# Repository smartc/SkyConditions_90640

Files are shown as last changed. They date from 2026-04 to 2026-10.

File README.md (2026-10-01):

# SkyConditions_90640

ESP32-S3 ASCOM Alpaca **ObservingConditions** device using an MLX90640 32×24 infrared thermal camera and TSL2591 sky brightness sensor.  Provides a fully standards-compliant Alpaca API for sky temperature, cloud cover, sky brightness, and sky quality monitoring — plus a live thermal viewer and trend charts in the browser.

**Current version: 0.6.3**

---

## Features

- **ASCOM Alpaca ObservingConditions** (device 0, port 11111, Interface v1)
  - SkyTemperature, Temperature, CloudCover, SkyBrightness, SkyQuality, Humidity (when DHT/BME280 enabled)
  - TimeSinceLastUpdate (all sensors, including LatestUpdateTime via empty SensorName)
  - SensorDescription, AveragePeriod, Refresh
- **ASCOM Alpaca SafetyMonitor** (device 0, port 11111, Interface v1)
  - IsSafe backed by rain/snow relay sensor; hidden from discovery when rain sensor is disabled
- **ASCOM Alpaca Switch** (device 0, port 11111, ISwitchV2)
  - One read-only analog switch: cloud cover percentage (0–100%), GetSwitch=true when ≥ 50%
- **UDP discovery** on port 32227 — runs on FreeRTOS Core 0 (independent of sensor reads)
- **Dual cloud cover calculation**
  - *Mean method*: linear interpolation on the center-FOV average ambient−sky delta
  - *Per-pixel method*: per-pixel interpolation across a configurable region, then averaged
  - Both methods trended simultaneously; Setup page toggle selects which value is reported to Alpaca
  - Live thermal view bounding box tracks the configured per-pixel region
- **Optional rain / snow sensor** — two-pin relay detection; relay closure = wet
- **DDA-compatible Safety Sensor UDP broadcast** — periodically broadcasts rain safety status on the local subnet in the Dark Dragon Astronomy park-sensor JSON format, allowing devices such as a Roll-Off Roof controller to discover the sensor and react to weather conditions automatically; port, interval, and enable state are runtime-configurable
- **Optional ambient sensor** — runtime-selectable: DHT11, DHT22, BMP180, BMP280, or BME280; replaces MLX90640 die temp as ambient reference for cloud cover calculations
- **MQTT / Home Assistant autodiscovery** — publishes all sensor values + thermal thumbnail; HA entities created automatically on connect
- **ClearDarkSky colormap** for the thermal heatmap — dark navy (clear/cold) through white (overcast/warm), anchored to calibration thresholds (floating) or a fixed °C range with a warm tail (default −45 … +60 °C, ending in red); a colour bar beside the live view shows the scale
- **Live thermal WebSocket stream** on port 81 — 784-byte binary frames at 2 Hz, bicubic-smoothed in the browser
- **Browser UI** on port 80
  - Home page: current readings, live thermal image, dual cloud cover values, brightness, rain status, humidity
  - Trends page: 60-min and 24-h charts for all sensors
  - Sky History page (`/skyhistory`): 90-day month calendar with Rain / SQM (night) / Clear Sky views — accumulated rain duration, night sky-quality average & peak, and day/night clear-sky hours — in the browser's local time zone, with CSV export
  - Setup page: full calibration, sensor enable/type selection, MQTT, NTP, network settings, WiFi scan & reconnect
  - Debug console (`/console`): live serial log with deduplication and copy button
- **Raw thermal matrix endpoint** — `GET /thermalmatrix` returns the full 32×24 temperature array as JSON
- **OTA firmware updates** via ElegantOTA at `/update`
- **WiFi management** — scan for networks and reconnect without a full credential reset (Setup page → WiFi)
- **History ring buffers**: 30-second buckets (60 min hi-res) + 15-minute buckets (24 h lo-res)
- **Persistent sky history**: hourly rain wet-time, night SQM avg/peak, and day/night clear-sky-hours logs covering 90 days, survives reboot, backing the Sky History calendar
- Persistent configuration in NVS flash (survives reboots)
- Passes ASCOM Conform Universal 4.2.1 with **0 errors, 0 issues** on all three devices

---

## Hardware

### Supported Boards

| Board | Notes |
|---|---|
| **Seeed XIAO ESP32-S3 Sense Plus** + Grove Shield | Primary target (`#define BOARD_XIAO_SENSE` in `config.h`) |
| ESP32-S3 Dev Module | Alternate; comment out `BOARD_XIAO_SENSE` |

Enable **PSRAM** in board settings — the thermal JPEG staging buffer requires ~230 KB.

### Sensors

| Component | Part | I2C Address |
|---|---|---|
| Thermal camera | Melexis MLX90640 32×24 IR array | 0x33 |
| Sky brightness | AMS TSL2591 | 0x29 |
| Ambient (optional) | DHT11 / DHT22 / BMP180 / BMP280 / BME280 | GPIO or I2C |

### Wiring (XIAO ESP32-S3 Sense + Grove Shield)

| Signal | XIAO Pin | GPIO |
|---|---|---|
| I2C SDA | D4 | GPIO 5 |
| I2C SCL | D5 | GPIO 6 |
| Rain relay drive | D8 | GPIO 7 |
| Rain relay sense | D9 | GPIO 8 |
| DHT data | D7 | GPIO 44 |

The rain sensor uses two pins: drive pin is held OUTPUT HIGH; relay closure pulls the sense pin HIGH (INPUT_PULLDOWN).  No external components required.

BMP180 / BMP280 / BME280 share the existing I2C bus — no extra GPIO needed.

### Wiring (ESP32-S3 Dev Module)

| Signal | GPIO |
|---|---|
| I2C SDA | GPIO 8 |
| I2C SCL | GPIO 9 |

---

## 3D-Printed Enclosure

The `Enclosure/` directory contains STL files and a master 3MF project for the weatherproof housing.  The design is sized for a **Seeed XIAO ESP32-S3** mounted on the **Grove Expansion Board**.

### Print Files

| File | Material | Notes |
|---|---|---|
| `Housing - Base.stl` | ASA or PETG | Main enclosure body |
| `Housing - Top.stl` | ASA or PETG | Lid |
| `Housing - Bracket.stl` | ASA or PETG | Mounting bracket |
| `Housing - Bracket Clamp.stl` | ASA or PETG | Bracket clamp |
| `Housing - Plug.stl` | ASA or PETG | Port plug |
| `Sensor Insert Plate.stl` | ASA or PETG | Sensor mounting plate |
| `Stevenson Screen.stl` | ASA or PETG | Stevenson radiation shield (requires supports) |
| `Stevenson Screen - Base Cap.stl` | ASA or PETG | Base cap for Stevenson screen |
| `TPU Housing Body Gasket.stl` | TPU | Weatherproof lid seal |
| `TPU Sensor Insert Gasket.stl` | TPU | Sensor plate seal |
| `TPU Cable Grommet.stl` | TPU | Cable entry grommet |
| `Sky Conditions 90640 - Enclosure.3mf` | — | Master 3MF project (all parts, orientations, materials) |

### Assembly Notes

- **Material:** Print structural parts in **ASA** (preferred outdoors) or **PETG**.  Print gaskets and grommets in **TPU**.
- **Stevenson screen:** Requires supports due to overhangs.
- **Heatset inserts required:**

  | Size | Location |
  |------|----------|
  | M3 | Lid-to-body and bracket fasteners |
  | M2.5 | PCB/expansion board mounting |
  | M2 | Sensor plate and smaller internal fasteners |

- **Fasteners:** Matching M3 / M2.5 / M2 socket-head or pan-head screws.
- **Lens holder:** The Uxcell 20 mm LED lens holder is glued into the top of the housing directly over the TSL2591.
- **Strain relief:** A 3/8″ PVC strain relief fitting is used for the MLX90640 cable entry.

---

## Bill of Materials

| Component | Part | Notes |
|---|---|---|
| Microcontroller | Seeed XIAO ESP32-S3 | |
| Expansion board | Seeed Grove Expansion Board for XIAO | Provides I2C headers and convenient wiring |
| Thermal camera | MLX90640 (TO-92 can format) | I2C, 32×24 IR array |
| Sky brightness | Adafruit TSL2591 | I2C, auto-gain |
| Rain / snow sensor | Relay-based heated sensor | [AliExpress](https://www.aliexpress.com/item/1005005479538840.html) |
| Lens holder | Uxcell 20 mm LED lens holder | [Amazon](https://a.co/d/01UBlwtW) — glued over TSL2591 aperture |
| Strain relief | 3/8″ PVC strain relief fitting | MLX90640 cable entry |
| Hookup wire | 22–26 AWG | I2C bus, sensor connections |

---

## Required Libraries

Install via Arduino IDE Library Manager unless noted:

| Library | Source |
|---|---|
| Adafruit MLX90640 | Library Manager |
| Adafruit TSL2591 | Library Manager |
| Adafruit BMP085 Unified | Library Manager (BMP180 support) |
| Adafruit BMP280 | Library Manager (BMP280 support) |
| Adafruit BME280 | Library Manager (BME280 support) |
| DHT sensor library (Adafruit) | Library Manager |
| WiFiManager (tzapu) | Library Manager |
| arduinoWebSockets (Markus Sattler) | Library Manager |
| ElegantOTA | Library Manager |
| ArduinoJson | Library Manager |
| **PubSubClient** | **Bundled** — `PubSubClient.h/.cpp` in project root |

---

## Build & Flash

1. Open `SkyConditions_90640.ino` in Arduino IDE 2.x
2. Select board: **XIAO_ESP32S3** or **ESP32S3 Dev Module**
3. Enable **PSRAM** in board settings
4. Select the correct port
5. Upload

---

## First Boot / WiFi Setup

On first boot (or after a full WiFi reset) the device creates a captive-portal access point:

- **SSID:** `SkyCond-Setup`
- **Password:** `skycond123`

Connect, choose your home network, and the device restarts and joins it.  The assigned IP is shown on the serial monitor.

To change the WiFi network without a full reset, use **Setup → WiFi → Scan for Networks**, select the target AP, enter the password, and click **Change WiFi**.  The device reconnects in place; credentials are persisted to NVS.

---

## ASCOM Alpaca Interface

All three devices are served on port **11111**.  Setup/UI URLs on port 11111 redirect to the web UI on port 80.

### ObservingConditions (device 0)

| ASCOM Property | Source | Notes |
|---|---|---|
| `SkyTemperature` | MLX90640 | Average of center 16×12 (192) pixels |
| `Temperature` | MLX90640 / ambient sensor | Die temp, or ambient sensor reading when enabled and valid |
| `CloudCover` | MLX90640 | Configurable: mean or per-pixel method (Setup page) |
| `SkyBrightness` | TSL2591 | Broadband lux with auto-gain |
| `SkyQuality` | TSL2591 | mag/arcsec² from SQM formula |
| `Humidity` | DHT / BME280 | %RH — only implemented when a humidity-capable sensor is enabled |

DewPoint, Pressure, RainRate, StarFWHM, WindDirection, WindGust, WindSpeed return `NotImplementedException`.

### SafetyMonitor (device 0)

| Property | Behaviour |
|---|---|
| `IsSafe` | `true` = relay open (dry); `false` = relay closed (wet/rain) |

Hidden from Alpaca discovery when the rain sensor is disabled in Setup.

### Switch (device 0) — Cloud Cover Indicator

| Switch | Name | Type | Range | Notes |
|---|---|---|---|---|
| 0 | Cloud Cover | Analog, read-only | 0–100 | Same value as `CloudCover`; `GetSwitch` = true when ≥ 50% |

### Discovery

UDP discovery (port 32227) runs in a dedicated FreeRTOS task pinned to Core 0 so it responds immediately regardless of sensor read timing on Core 1.

---

## Web UI

| URL | Content |
|-----|---|
| `http://<ip>/` | Live status: temperatures, cloud cover, lux/SQM, rain, humidity, thermal image |
| `http://<ip>/trends` | 60-min and 24-h trend charts |
| `http://<ip>/skyhistory` | 90-day Sky History calendar (Rain / SQM / Clear Sky views) |
| `http://<ip>/skyhistory.json?days=N` | Raw hourly rain/SQM/clear-sky JSON (N = 1–90) |
| `http://<ip>/setup` | Configuration form |
| `http://<ip>/console` | Live serial debug console |
| `http://<ip>/thermal.jpg` | Latest thermal JPEG snapshot |
| `http://<ip>/thermalmatrix` | Raw 32×24 temperature matrix as JSON |
| `http://<ip>/history.json?minutes=N` | Raw history JSON (N = 5–1440) |
| `http://<ip>/update` | ElegantOTA firmware update |
| `http://<ip>/wifi/scan` | GET — JSON array of nearby WiFi networks |
| `http://<ip>/wifi/connect` | POST (ssid, password) — reconnect without credential reset |
| `http://<ip>/reset_wifi` | POST — clear WiFi credentials and restart |

WebSocket live stream: `ws://<ip>:81` — 784-byte binary frames (see below).

---

## WebSocket Frame Format (784 bytes)

| Bytes | Type | Content |
|---|---|---|
| 0–3 | float32 | Frame minimum temperature (°C) |
| 4–7 | float32 | Frame maximum temperature (°C) |
| 8–11 | float32 | Frame median temperature (°C) |
| 12–15 | float32 | Sky temperature — center 50% FOV average (°C) |
| 16–783 | uint8 × 768 | Palette index per pixel: 0–254 across the heatmap display range, 255 = above the "hot" threshold (optional, off by default) |

---

## MQTT / Home Assistant

Enable in Setup → MQTT.  The device publishes to `<prefix>/state` every 30 seconds and on reconnect, and sends a thermal thumbnail to `<prefix>/thumbnail`.  Home Assistant discovery entities are published automatically on connect.

**State payload (JSON):**
```json
{
  "sky_temp": -12.5,    "ambient_temp": 18.2,
  "frame_min": -18.0,   "frame_max": 25.0,   "frame_median": 4.3,
  "cloud_cover": 35.0,  "cloud_cover_mean": 35.0, "cloud_cover_pixel": 32.1,
  "lux": 0.0023,        "sqm": 21.5,
  "has_data": true,     "has_brightness": true,
  "ip": "192.168.x.x",  "version": "0.6.3"
}
```

**HA entities auto-created:** sky_temperature, ambient_temperature, cloud_cover, cloud_cover_mean, cloud_cover_pixel, sky_brightness, sky_quality, frame_min/max/median_temp, sky_thermal_image.

The topic prefix defaults to `skyconditions-<MAC>` to avoid broker collisions.  Override it in Setup → MQTT.

---

## Cloud Cover

Two methods run on every frame and are trended independently:

**Mean method** — computes a single ambient−sky delta using the center-FOV (16×12 pixel) average, then linearly interpolates to 0–100%.

**Per-pixel method** — applies the same interpolation to each pixel in the selected region, then averages the results.

Region options (Setup page): *Centre FOV* (192 pixels) or *Full Frame* with a configurable edge exclusion border.

The **Cloud Cover Method** toggle on the Setup page selects which value is reported to ASCOM Alpaca.  Both are always shown on the home page and in trend charts.  The red bounding box in the live thermal view tracks the per-pixel region.

---

## Configuration (Setup Page)

| Setting | Default | Description |
|---|---|---|
| SQM Offset | 0.0 | Additive offset on SQM readings (mag/arcsec²) |
| SQM Reference | 108000 lux | Lux level that maps to SQM 0.0 |
| Cloud Clear Delta | 20 °C | Ambient−sky delta at which sky is 0% cloud |
| Cloud Overcast Delta | 5 °C | Ambient−sky delta at which sky is 100% cloud |
| Night Lux Threshold | 1.0 lux | Below this = "night" for Sky History SQM/clear-sky-night tracking |
| Clear-Sky Cloud Threshold | 20% | Below this cloud cover = "clear" for Sky History tracking |
| Cloud Cover Method | Mean | Selects mean or per-pixel value for Alpaca |
| Per-Pixel Region | Centre FOV | Region for per-pixel method |
| Edge Exclusion | 2 px | Pixels excluded per edge in Full Frame mode |
| Rain Sensor | Enabled | Enable/disable relay-based rain detection |
| Ambient Sensor | Disabled | Sensor type: Disabled / DHT11 / DHT22 / BMP180 / BMP280 / BME280 |
| Snapshot Interval | 30 s | Thermal JPEG refresh period |
| JPEG Quality | 80 | JPEG encoding quality (1–100) |
| TSL2591 Integration | 300 ms | Integration time for the brightness sensor |
| Average Period | 0.5 s | ASCOM ObservingConditions AveragePeriod |
| Location | Observatory | Shown in Alpaca management API |
| NTP Server | *(blank)* | Preferred NTP server (blank = pool.ntp.org) |
| MQTT Enabled | false | Enable MQTT publishing |
| MQTT Server | *(blank)* | Broker hostname or IP |
| MQTT Port | 1883 | Broker port |
| MQTT User / Password | *(blank)* | Broker credentials |
| MQTT Topic Prefix | skyconditions-*mac* | Topic prefix (auto-suffixed with MAC if unchanged) |
| Safety Broadcast | Disabled | Broadcast rain safety status via UDP (DDA park-sensor protocol) |
| Safety Broadcast Port | 23435 | UDP destination port for safety broadcasts |
| Safety Broadcast Interval | 30 s | Keep-alive broadcast interval; immediate send on state change (min 5 s) |

All settings persist to NVS flash across reboots.

---

## Port Summary

| Port | Protocol | Purpose |
|---|---|---|
| 80 | HTTP | Web UI |
| 81 | WebSocket | Live thermal binary stream |
| 11111 | HTTP | ASCOM Alpaca API (all three devices) |
| 32227 | UDP | Alpaca discovery |
| 23435 | UDP broadcast | DDA-compatible safety sensor status (configurable) |

---

## File Structure

```
SkyConditions_90640/
├── SkyConditions_90640.ino       Entry point: WiFi, sensor init, main loop
├── config.h                      Compile-time constants (pins, ports, frame geometry, version)
├── config_store.h/.cpp           NVS persistent config load/save
├── tools/
│   └── udp_monitor.py            Python listener for UDP safety broadcasts (testing)
└── src/
    ├── debug/                    Conditional serial debug wrapper
    ├── alpaca/                   ASCOM Alpaca HTTP server (port 11111) + UDP discovery
    ├── sensors/
    │   ├── sky_sensor            SkyConditions class — MLX90640, dual cloud cover, colormap
    │   ├── dht_sensor            Optional ambient sensor: DHT11/22, BMP180, BMP280, BME280
    │   ├── rain_sensor           Two-pin relay + RS485 Modbus rain/snow detection
    │   ├── history               Dual-resolution history ring buffers (30 s / 15 min)
    │   └── sky_history            Persistent 90-day hourly rain/SQM/clear-sky history (NVS-backed)
    ├── webserver/
    │   ├── web_ui_handler        HTTP server (port 80) + WebSocket server (port 81)
    │   └── html_templates        Inline HTML/CSS/JS for browser pages
    ├── mqtt/
    │   ├── mqtt_handler          MQTT client + Home Assistant autodiscovery
    │   └── PubSubClient          Bundled MQTT client library
    ├── safety/
    │   └── rain_safety_broadcast DDA-compatible safety sensor UDP broadcast
    └── watchdog/                 Heap monitor / periodic health log
```

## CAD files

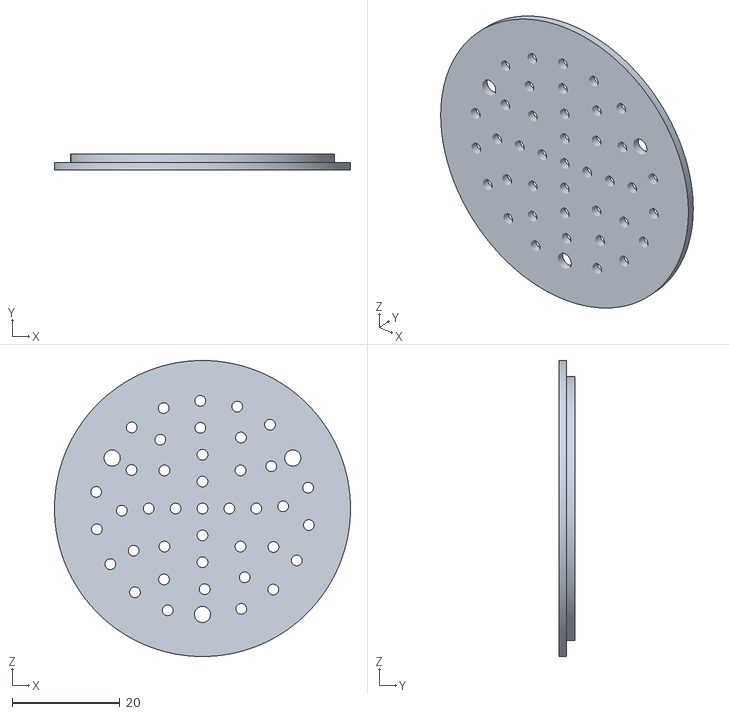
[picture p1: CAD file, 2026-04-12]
Enclosure/Bottom Cap.stl
55.0 x 2.90 x 55.0

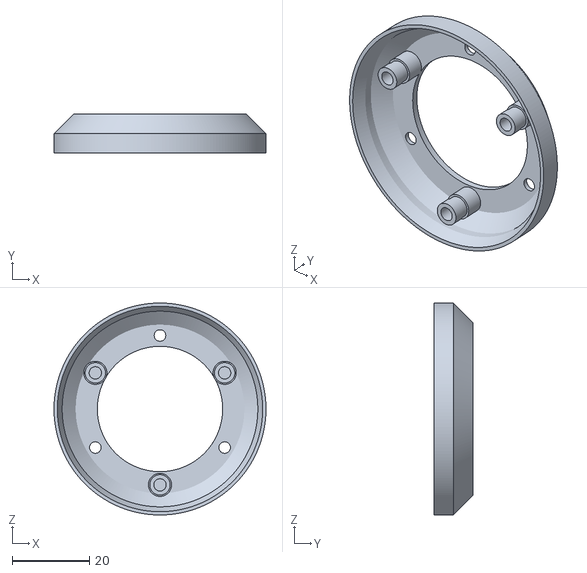
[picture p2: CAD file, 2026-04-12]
Enclosure/Ring Fin.stl
55.0 x 10.0 x 55.0

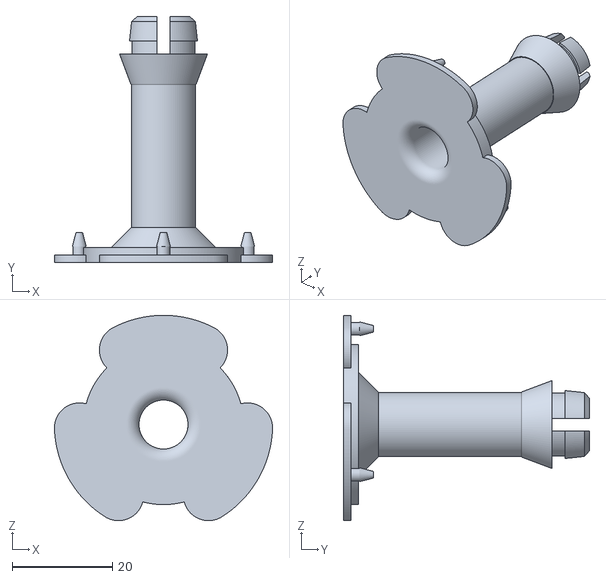
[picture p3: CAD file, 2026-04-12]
Enclosure/Neck.stl
43.5 x 49.0 x 40.9

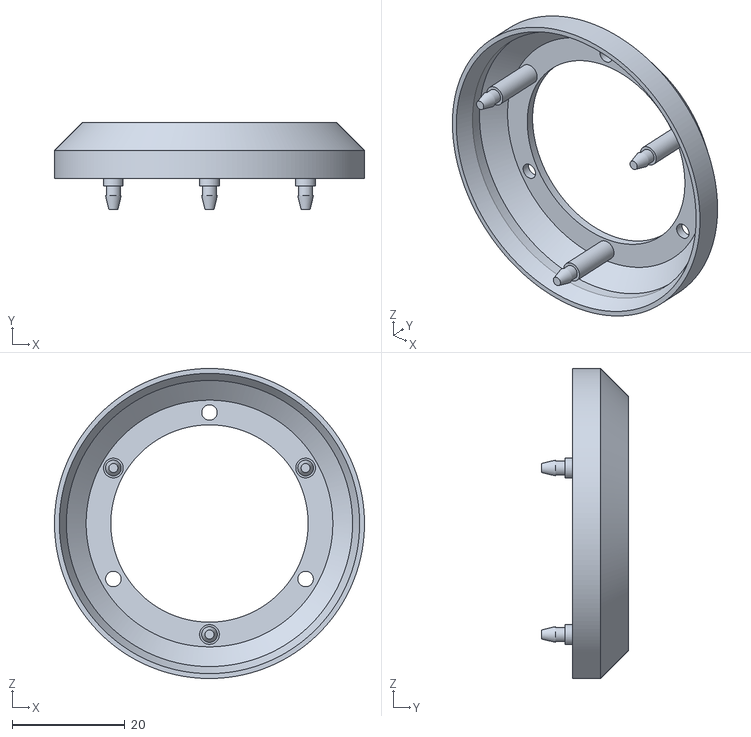
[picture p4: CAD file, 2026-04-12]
Enclosure/Fin Ring.stl
55.0 x 15.5 x 55.0

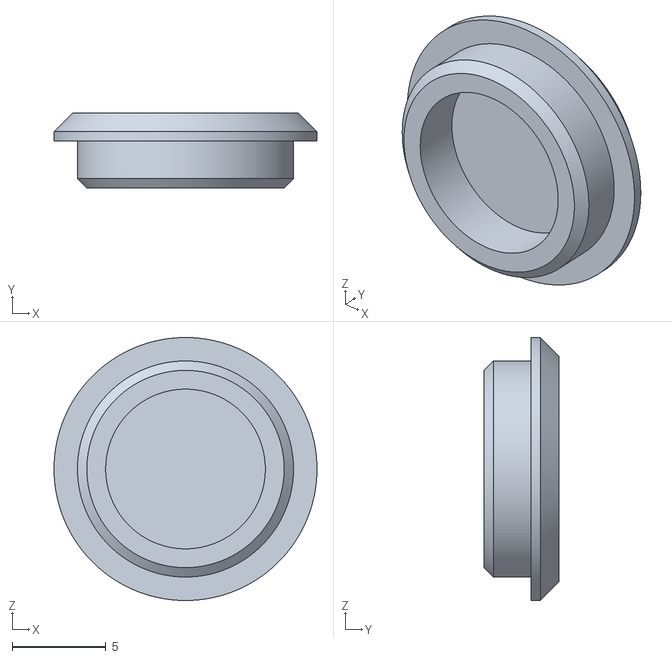
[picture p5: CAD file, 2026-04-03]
Enclosure/Housing - Plug.stl
14.0 x 4.00 x 14.0

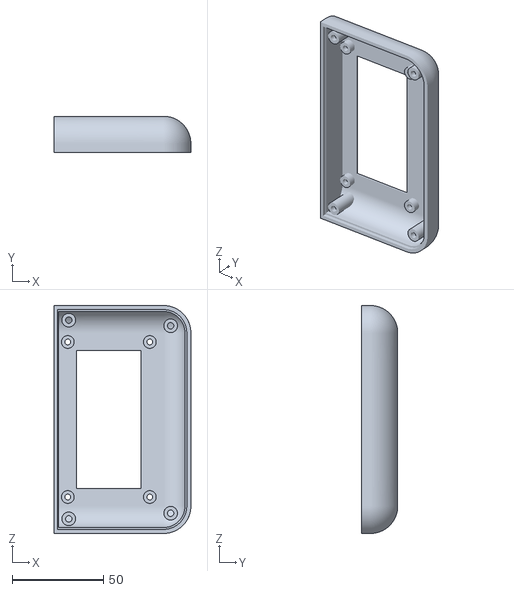
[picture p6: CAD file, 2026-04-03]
Enclosure/Housing - Top.stl
75.0 x 20.0 x 125.0

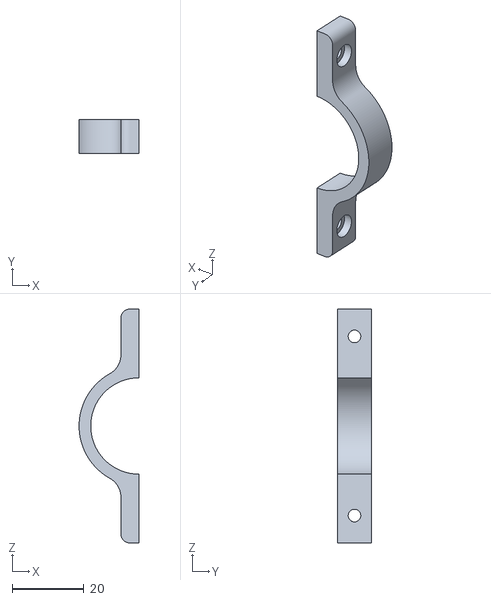
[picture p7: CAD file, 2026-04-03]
Enclosure/Housing - Bracket Clamp.stl
16.6 x 9.50 x 65.0

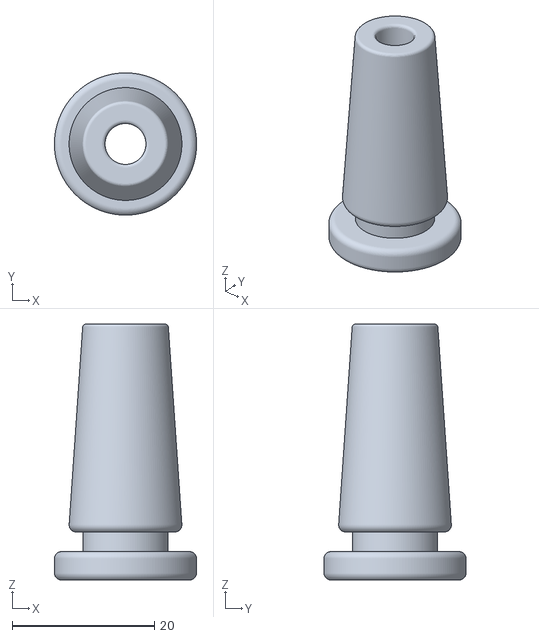
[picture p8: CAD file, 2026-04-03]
Enclosure/TPU Cable Grommet.stl
20.0 x 20.0 x 36.0

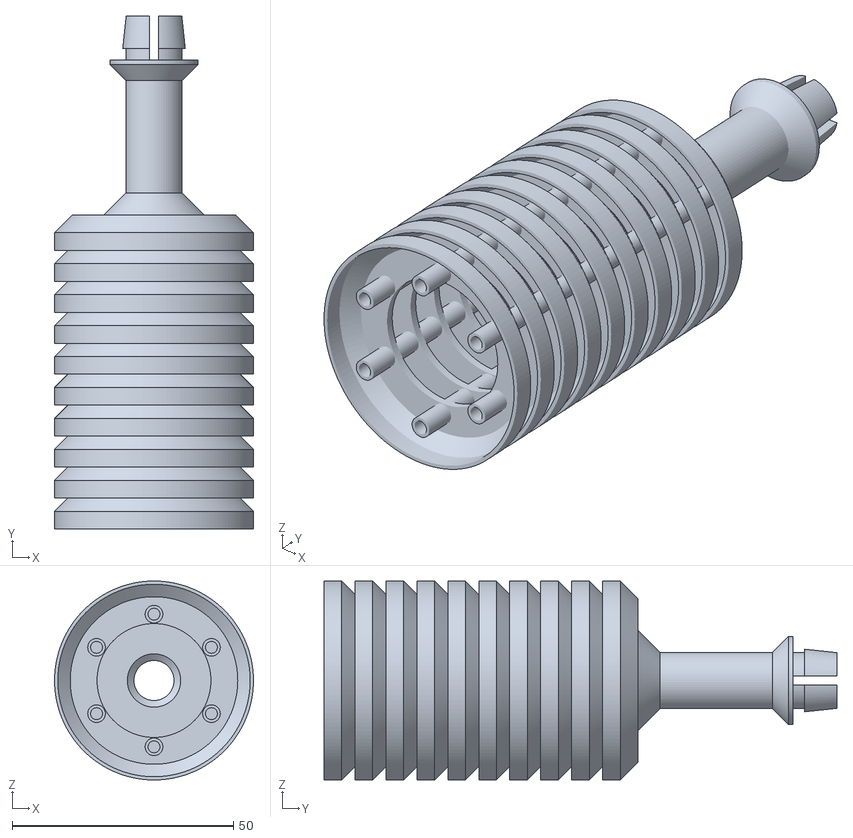
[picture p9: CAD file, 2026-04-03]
Enclosure/Stevenson Screen.stl
45.0 x 116.0 x 45.0

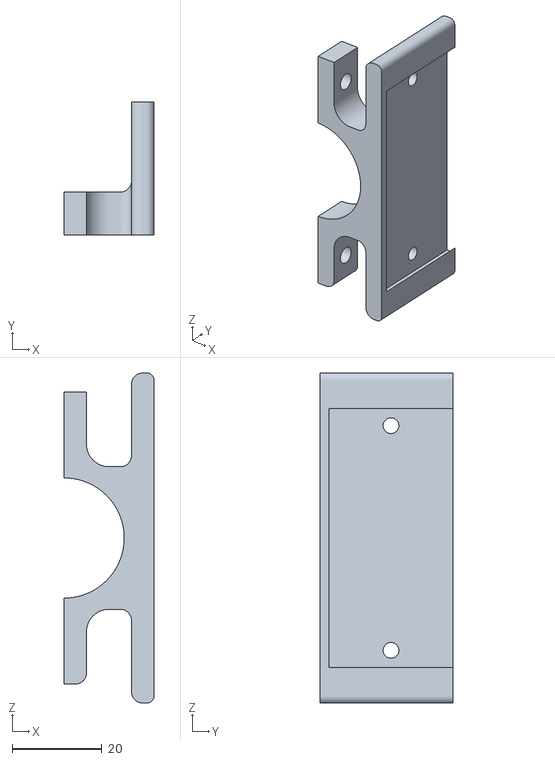
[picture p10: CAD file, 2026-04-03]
Enclosure/Housing - Bracket.stl
20.0 x 29.5 x 73.4

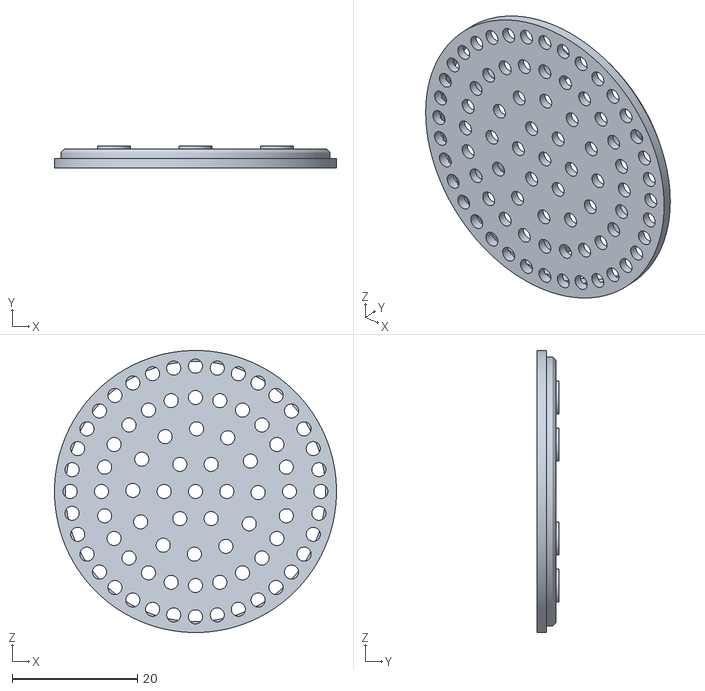
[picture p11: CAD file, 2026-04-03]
Enclosure/Stevenson Screen - Base Cap.stl
45.0 x 3.50 x 45.0

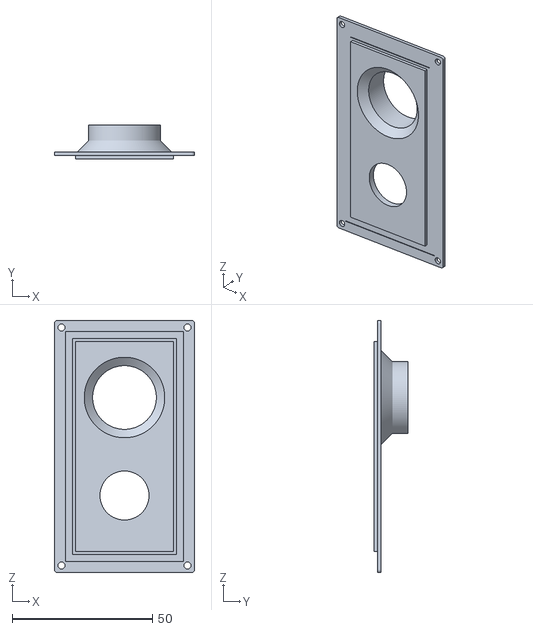
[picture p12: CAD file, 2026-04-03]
Enclosure/Sensor Insert Plate.stl
50.0 x 12.0 x 90.0

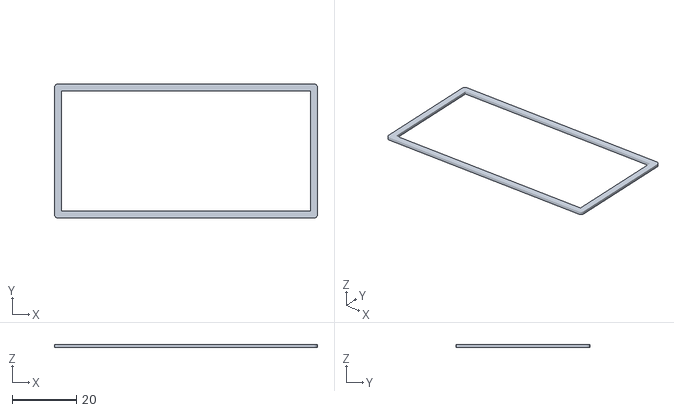
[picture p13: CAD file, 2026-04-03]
Enclosure/TPU Sensor Insert Gasket.stl
81.7 x 41.7 x 1.00

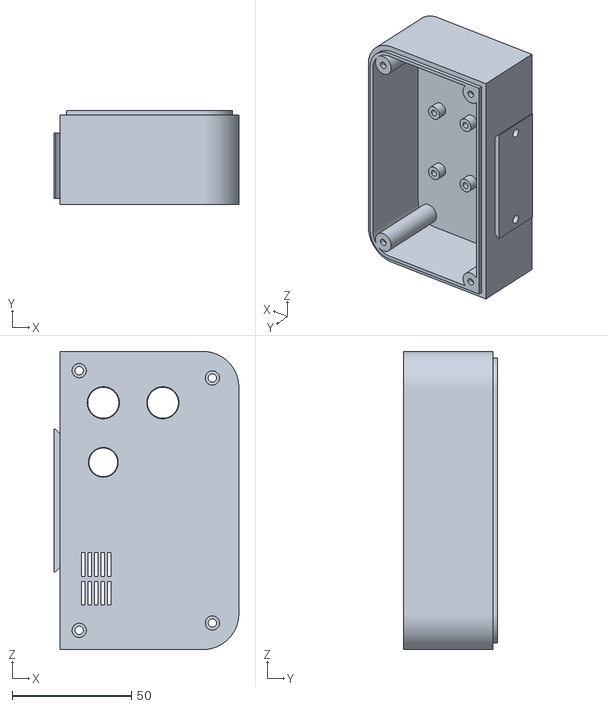
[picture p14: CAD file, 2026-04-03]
Enclosure/Housing - Base.stl
77.5 x 39.5 x 125.0

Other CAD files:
Enclosure/Sky Conditions 90640 - Enclosure.3mf
Enclosure/TPU Housing Body Gasket.stl

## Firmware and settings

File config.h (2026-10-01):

#ifndef CONFIG_H
#define CONFIG_H

// ── Board Selection ───────────────────────────────────────────────────────────
// Auto-detected from Tools > Board in the Arduino IDE, via the board macro the
// esp32 core defines at compile time for whichever board is currently
// selected there — so this no longer has to be hand-toggled to match what's
// actually flashed (which is how it went stale in the first place).
//
// To force a profile regardless of auto-detection (e.g. a board variant the
// check below doesn't recognise), uncomment exactly one line here — it takes
// priority over the auto-detect block that follows.
// #define BOARD_XIAO_SENSE
// #define BOARD_ESP32S3_DEV

#if !defined(BOARD_XIAO_SENSE) && !defined(BOARD_ESP32S3_DEV)
  #if defined(ARDUINO_XIAO_ESP32S3)
    #define BOARD_XIAO_SENSE
  #else
    // Falls back to the Dev Module pinout for ESP32S3 Dev Module and for any
    // board the check above doesn't recognise. BOARD_AUTO_FALLBACK flags the
    // latter case so it's visible (Setup page / boot log) rather than a
    // silent guess — compare IDE_BOARD_ID there against what you expect.
    #define BOARD_ESP32S3_DEV
    #if !defined(ARDUINO_ESP32S3_DEV)
      #define BOARD_AUTO_FALLBACK
    #endif
  #endif
#endif

// Raw board id the Arduino build system passes in for whatever is selected
// in Tools > Board – always accurate, needs no maintenance as boards are
// added. ARDUINO_BOARD is a standard macro across Arduino cores.
#if defined(ARDUINO_BOARD)
  #define IDE_BOARD_ID  ARDUINO_BOARD
#else
  #define IDE_BOARD_ID  "unknown (ARDUINO_BOARD not defined by this core)"
#endif

// MLX90640 I2C Configuration
#if defined(BOARD_XIAO_SENSE)
  #define THERMAL_SDA_PIN   5    // GPIO5 = D4 pad on XIAO ESP32-S3 Sense
  #define THERMAL_SCL_PIN   6    // GPIO6 = D5 pad on XIAO ESP32-S3 Sense
  #define BOARD_NAME        "Seeed XIAO ESP32-S3 Sense"
#else
  #define THERMAL_SDA_PIN   8    // GPIO8 on ESP32-S3 Dev Module
  #define THERMAL_SCL_PIN   9    // GPIO9 on ESP32-S3 Dev Module
  #define BOARD_NAME        "ESP32-S3 Dev Module"
#endif
#if defined(BOARD_XIAO_SENSE)
  #define THERMAL_I2C_FREQ  100000   // 100 kHz – XIAO header has no external pull-ups
#else
  #define THERMAL_I2C_FREQ  400000   // 400 kHz
#endif

// MLX90640 Sensor Geometry
#define SENSOR_COLS         32
#define SENSOR_ROWS         24
#define SENSOR_PIXELS       768      // 32 * 24

// Center 50% FOV Region (center half of each dimension = 16x12 pixels)
// Row-major order: pixel index = row * SENSOR_COLS + col
#define CENTER_COL_START    8        // Columns 8..23 = 16 cols (50% of 32)
#define CENTER_COL_END      23
#define CENTER_ROW_START    6        // Rows 6..17   = 12 rows (50% of 24)
#define CENTER_ROW_END      17
#define CENTER_PIXEL_COUNT  192      // 16 * 12

// Sensor Refresh
#define FRAME_INTERVAL_MS       5000   // 5 s (MLX90640)
#define BRIGHTNESS_INTERVAL_MS  5000   // 5 s (TSL2591)
#define JPEG_INTERVAL_MS        30000  // 30 s  thermal JPEG snapshot

// Ambient temperature sensor (optional – see dht_sensor.h/.cpp)
// Sensor type is selected at runtime via Setup page → ambientSensorType (NVS key "dhtType"):
//   0 = disabled, 1 = DHT11, 2 = DHT22, 3 = BMP180
//
// DHT11/DHT22 use the D6/D7 Grove connector; data line on D7 (GPIO44, UART0 RX).
// BMP180 is I2C – shares the existing SDA/SCL bus (no extra GPIO needed), addr 0x77.
#if defined(BOARD_XIAO_SENSE)
  #define DHT_DATA_PIN   44    // D7 = GPIO44
#else
  #define DHT_DATA_PIN   (-1)  // not assigned for Dev board – define as needed
#endif
#define DHT_INTERVAL_MS   5000  // match sensor read rate; DHT11 minimum is 1 s
#define BMP180_I2C_ADDR   0x77  // BMP180 default I2C address
#define BMP280_I2C_ADDR   0x76  // BMP280 default I2C address (SDO→GND); use 0x77 if SDO→VCC

// ASCOM Alpaca Configuration
#define ALPACA_PORT           11111
#define ALPACA_DISCOVERY_PORT 32227

// Device Information
#define SERVER_NAME       "SkyConditions_90640"
#define MANUFACTURER      "Corey Smart"
#define MANUFACTURER_V    "0.6.3"
#define LOCATION          "Observatory"
#define DEVICE_NAME       "MLX90640 Sky Conditions Sensor"
#define DESCRIPTION       "ESP32-S3 ASCOM Alpaca ObservingConditions device using MLX90640 thermal camera"
#define DEVICE_TYPE       "observingconditions"
#define DEVICE_NUMBER     0

// Rain / Snow Sensor (ZTS-3000-YUX-NO1RO1-H, MAX3485ED transceiver)
//
// Relay wiring varies by board:
//   XIAO Grove Shield: relay bridged between D8 and D9.
//     DRIVE pin (D8/GPIO7) → OUTPUT HIGH feeds one relay contact.
//     SENSE pin (D9/GPIO8) → INPUT_PULLDOWN; reads HIGH when relay closes (wet).
//   ESP32-S3 Dev: relay contact pulls IO38 to GND (original single-pin scheme).
//     DRIVE pin not used (-1).
//     SENSE pin (IO38) → INPUT_PULLUP; reads LOW when relay closes (wet).
#if defined(BOARD_XIAO_SENSE)
  #define RAIN_RELAY_DRIVE_PIN  7    // D8 = GPIO7: OUTPUT HIGH, drives relay contact
  #define RAIN_RELAY_SENSE_PIN  8    // D9 = GPIO8: INPUT_PULLDOWN; HIGH = wet
#else
  #define RAIN_RELAY_DRIVE_PIN  (-1) // not used; relay return is GND
  #define RAIN_RELAY_SENSE_PIN  38   // IO38: INPUT_PULLUP; LOW = wet
#endif
#define RAIN_RS485_DE_PIN    39    // IO39: MAX3485ED DE/RE# (HIGH=TX, LOW=RX)
#define RAIN_RS485_TX_PIN    40    // IO40: MAX3485ED DI  (ESP32 → sensor)
#define RAIN_RS485_RX_PIN    41    // IO41: MAX3485ED RO  (sensor → ESP32)
#define RAIN_BAUD_RATE       9600
#define RAIN_MODBUS_ADDR     0x01  // Default slave address per datasheet
#define RAIN_POLL_MS         5000  // Modbus poll interval (ms)


// Safety Sensor UDP Broadcast (DDA-compatible park-sensor protocol)
#define RAIN_SAFETY_DEVICE_TYPE           "SafetySensor"
#define RAIN_SAFETY_UDP_PORT_DEFAULT      23435
#define RAIN_SAFETY_INTERVAL_DEFAULT_SEC  30

// Preferences Namespace
#define PREFERENCES_NAMESPACE "skyCond"

// Rain History – persistent per-hour wet-time log, rendered as a 90-day calendar.
#define RAIN_HIST_DAYS              90
#define RAIN_HIST_RING_HOURS        (RAIN_HIST_DAYS * 24)   // 2160 hourly buckets
#define RAIN_HIST_MIN_VALID_EPOCH   1700000000UL            // clock treated as synced once past this (2023-11-14)
#define RAIN_HIST_NAMESPACE         "rainHist"

// MQTT Configuration
#define DEFAULT_MQTT_SERVER        ""
#define DEFAULT_MQTT_PORT          1883
#define DEFAULT_MQTT_USER          ""
#define DEFAULT_MQTT_PASSWORD      ""
#define DEFAULT_MQTT_TOPIC_PREFIX  "skyconditions"
#define DEFAULT_MQTT_KEEPALIVE     60       // seconds; LWT fires after ~1.5×
#define MQTT_PUBLISH_INTERVAL      30000    // ms between periodic state publishes
#define MQTT_SERVER_SIZE           64
#define MQTT_USER_SIZE             32
#define MQTT_PASSWORD_SIZE         64
#define MQTT_TOPIC_SIZE            80

// Thermal JPEG snapshot scale factor (applied before JPEG encoding).
// scaledBuf is placed in PSRAM (EXT_RAM_BSS_ATTR) so internal heap is unaffected.
// 10 → 320×240 px (~230 KB staging in PSRAM).  Requires PSRAM enabled in board settings.
#define THERMAL_JPEG_SCALE  10

// Heatmap palette (display only – cloud cover never uses these).
// In fixed mode the blue→white sky palette runs from heatmapFixedMin up to
// HEATMAP_WARM_START_C, then a white→yellow→orange→red warm tail runs up to
// heatmapFixedMax; values beyond either end are clamped to the end colour.
// Optional hot-pixel marker (deviceConfig.heatmapHotMarker, runtime-toggled
// in Setup): when enabled, palette index HEATMAP_HOT_INDEX (magenta) marks
// pixels above the hot threshold – heatmapFixedMax in fixed mode, ambient +
// HEATMAP_HOT_MARGIN_C in floating mode – so a sub-pixel sun stands out
// instead of clamping.
#define HEATMAP_HOT_INDEX     255
#define HEATMAP_HOT_MARGIN_C  20.0f
#define HEATMAP_WARM_START_C   0.0f

// WebSocket binary frame layout (sent to browser)
// Bytes  0-3:  float32 min temperature (full frame)
// Bytes  4-7:  float32 max temperature (full frame)
// Bytes  8-11: float32 median temperature (full frame)
// Bytes 12-15: float32 sky temperature (center 50% FOV average)
// Bytes 16-783: uint8  palette index per pixel: 0..254 = position on the
//               heatmap display range, 255 = above the "hot" threshold
//               (only when deviceConfig.heatmapHotMarker is enabled)
#define WS_HEADER_SIZE      16
#define WS_FRAME_SIZE       (WS_HEADER_SIZE + SENSOR_PIXELS)  // 784 bytes

#endif // CONFIG_H

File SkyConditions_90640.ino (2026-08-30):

/*
 * ESP32-S3 MLX90640 Sky Conditions Sensor
 * ASCOM Alpaca ObservingConditions Device
 *
 * Provides:
 *   - ASCOM Alpaca ObservingConditions API (port 11111)
 *     SkyTemperature = average of center 50% FOV pixels
 *     Temperature    = sensor ambient/die temperature
 *   - Live thermal WebSocket stream (port 81, 784-byte binary frames at 2 Hz)
 *   - Web status/setup UI (port 80)
 *
 * Libraries required (install via Library Manager):
 *   - Adafruit MLX90640
 *   - WiFiManager (tzapu)
 *   - arduinoWebSockets (Markus Sattler)
 *   - ElegantOTA
 *   - ArduinoJson
 *
 * Board: ESP32S3 Dev Module (or compatible)
 */

#include "config.h"
#include "config_store.h"
#include "src/debug/debug.h"
#include "src/alpaca/alpaca.h"
#include "src/sensors/sky_sensor.h"
#include "src/sensors/dht_sensor.h"
#include "src/sensors/rain_sensor.h"
#include "src/sensors/history.h"
#include "src/sensors/sky_history.h"
#include "src/webserver/web_ui_handler.h"
#include "src/mqtt/mqtt_handler.h"
#include "src/safety/rain_safety_broadcast.h"
#include "src/watchdog/watchdog.h"

#include <Wire.h>
#include <Adafruit_MLX90640.h>
#include <Adafruit_TSL2591.h>
#include <WiFi.h>
#include <WiFiManager.h>
#include <ElegantOTA.h>

// ---------------------------------------------------------------------------
// Globals
// ---------------------------------------------------------------------------

// Singleton device object – declared extern in sky_sensor.h, defined here.
SkyConditions skyConditions;

// Thermal sensor (MLX90640)
static Adafruit_MLX90640 mlx;
static float thermalFrame[SENSOR_PIXELS];
static bool  sensorReady    = false;
static unsigned long lastSensorRead = 0;

// Brightness sensor (TSL2591)
static Adafruit_TSL2591 tsl(2591);
static bool  brightnessReady   = false;
static unsigned long lastBrightnessRead = 0;

// ---------------------------------------------------------------------------
// Forward declarations
// ---------------------------------------------------------------------------
void readSensor();
void readBrightness();

// ---------------------------------------------------------------------------
// setup()
// ---------------------------------------------------------------------------
void setup()
{
  Serial.begin(115200);
  delay(100);
  Debug.println("\nMLX90640 Sky Conditions Sensor – ASCOM Alpaca Driver v" MANUFACTURER_V);
  Debug.println("Board (Arduino IDE selection): " IDE_BOARD_ID);
#if defined(BOARD_AUTO_FALLBACK)
  Debug.println("WARNING: board id not recognised – defaulted pinout profile to " BOARD_NAME
                ". Verify I2C pins on /setup, or force a profile in config.h.");
#else
  Debug.println("Pinout profile (auto-detected): " BOARD_NAME);
#endif

  // ── I2C bus recovery (bit-bang) ───────────────────────────────────────────
  // If a previous boot crashed mid-transaction, a slave may be holding SDA low
  // (bus lockup). Send 9 SCL pulses to clock out the stuck byte, then a STOP
  // condition to release the bus, before handing control to Wire.
  {
    pinMode(THERMAL_SCL_PIN, OUTPUT);
    pinMode(THERMAL_SDA_PIN, INPUT_PULLUP);   // let slave release SDA naturally
    digitalWrite(THERMAL_SCL_PIN, HIGH);
    for (int i = 0; i < 9; i++) {
      digitalWrite(THERMAL_SCL_PIN, LOW);  delayMicroseconds(10);
      digitalWrite(THERMAL_SCL_PIN, HIGH); delayMicroseconds(10);
      if (digitalRead(THERMAL_SDA_PIN)) break;  // SDA released – bus is free
    }
    // Generate STOP: SDA LOW→HIGH while SCL is HIGH
    pinMode(THERMAL_SDA_PIN, OUTPUT);
    digitalWrite(THERMAL_SDA_PIN, LOW);  delayMicroseconds(10);
    digitalWrite(THERMAL_SCL_PIN, HIGH); delayMicroseconds(10);
    digitalWrite(THERMAL_SDA_PIN, HIGH); delayMicroseconds(10);
    // Release both pins before Wire takes over
    pinMode(THERMAL_SDA_PIN, INPUT);
    pinMode(THERMAL_SCL_PIN, INPUT);
    delay(10);
  }

  // ── I2C + sensors ─────────────────────────────────────────────────────────
  Wire.end();
  Wire.setPins(THERMAL_SDA_PIN, THERMAL_SCL_PIN);
  //Wire.begin(THERMAL_SDA_PIN, THERMAL_SCL_PIN);
  Wire.begin();
  Wire.setClock(THERMAL_I2C_FREQ);
  delay(50);

  // Multi-pair I2C pin scanner.
  // Tries every candidate SDA/SCL pair and reports which one sees the sensors.
  // Expected: MLX90640 = 0x33, TSL2591 = 0x29.
  {
    struct PinPair { int sda; int scl; const char *label; };
    static const PinPair candidates[] = {
      {  5,  6, "GPIO5/6  (XIAO D4/D5)" },
      {  6,  5, "GPIO6/5  (XIAO D4/D5 reversed)" },
      {  6,  7, "GPIO6/7  (XIAO D5/D6)" },
      {  7,  6, "GPIO7/6  (XIAO D5/D6 reversed)" },
      {  4,  5, "GPIO4/5  (XIAO D3/D4)" },
      {  5,  4, "GPIO5/4  (XIAO D3/D4 reversed)" },
      {  3,  4, "GPIO3/4  (XIAO D2/D3)" },
      {  4,  3, "GPIO4/3  (XIAO D2/D3 reversed)" },
      {  8,  9, "GPIO8/9  (ESP32-S3 Dev)" },
      {  9,  8, "GPIO9/8  (ESP32-S3 Dev reversed)" },
    };
    // Stop as soon as we find the sensors – scanning wrong pairs after a hit
    // drives the sensor's SCL/SDA lines as the opposite role, causing bus lockup.
    Debug.println("--- I2C pin scan (looking for 0x29/0x33) ---");
    bool pinsFound = false;
    for (const auto &p : candidates) {
      Wire.end();
      Wire.begin(p.sda, p.scl);
      Wire.setClock(100000);
      delay(20);
      Wire.beginTransmission(0x33); bool found33 = (Wire.endTransmission() == 0);
      Wire.beginTransmission(0x29); bool found29 = (Wire.endTransmission() == 0);
      if (found33 || found29) {
        Debug.printf("  *** HIT on %s: %s %s – initialising libraries now\n", p.label,
          found33 ? "MLX90640(0x33)" : "",
          found29 ? "TSL2591(0x29)"  : "");
        pinsFound = true;

        // Init libraries immediately while Wire is live on the correct pins.
        // TSL2591 first: its internal Wire.begin() reinit is survivable and
        // helps settle the bus before the more sensitive MLX90640 init.
        if (found29) {
          if (!tsl.begin(&Wire)) {
            Debug.println("WARNING: TSL2591 not found – check wiring!");
          } else {
            tsl.setGain(TSL2591_GAIN_MAX);
            tsl.setTiming(TSL2591_INTEGRATIONTIME_300MS);
            brightnessReady = true;
            Debug.println("TSL2591 initialised (MAX gain, 300 ms integration)");
          }
        }
        // MLX90640 after TSL2591 – retry a few times; the sensor may need a
        // moment to recover after the library's internal Wire.begin() reinit.
        if (found33) {
          for (int attempt = 1; attempt <= 5 && !sensorReady; attempt++) {
            if (attempt > 1) {
              Debug.printf("MLX90640 init retry %d/5...\n", attempt);
              delay(200);
            }
            if (mlx.begin(MLX90640_I2CADDR_DEFAULT, &Wire)) {
              mlx.setMode(MLX90640_CHESS);
              mlx.setResolution(MLX90640_ADC_18BIT);
              mlx.setRefreshRate(MLX90640_2_HZ);
              sensorReady = true;
              Debug.printf("MLX90640 initialised on attempt %d\n", attempt);
              mlx.getFrame(thermalFrame);
            }
          }
          if (!sensorReady) Debug.println("WARNING: MLX90640 not found – check wiring!");
        }
        break;
      } else {
        Debug.printf("      miss: %s\n", p.label);
      }
    }
    Debug.println("--- pin scan complete ---");
    if (!pinsFound) {
      Debug.println("WARNING: sensors not found on any pin pair");
    }
  }

  // ── WiFi via WiFiManager ──────────────────────────────────────────────────
  WiFiManager wifiManager;
  wifiManager.setConfigPortalTimeout(180);

  WiFiManagerParameter portalTitle("<p>MLX90640 Sky Conditions Sensor</p>");
  wifiManager.addParameter(&portalTitle);

  Debug.println("Connecting to WiFi (or launching setup portal)...");
  bool wifiOk = wifiManager.autoConnect("SkyCond-Setup", "skycond123");

  if (!wifiOk) {
    Debug.println("WiFi connection failed. Restarting in 3 s...");
    delay(3000);
    ESP.restart();
  }

  Debug.print("WiFi connected. IP: ");
  Debug.println(WiFi.localIP().toString());

  // ── Persistent config (calibration, thresholds) ──────────────────────────
  configLoad(deviceConfig);
  Debug.printf("Config: sqmOffset=%.2f  cloudClear=%.1f  cloudOvercast=%.1f\n",
    deviceConfig.sqmOffset, deviceConfig.cloudClearDelta, deviceConfig.cloudOvercastDelta);

  // ── NTP sync – system clock; configurable preferred server ───────────────
  if (strlen(deviceConfig.ntpServer) > 0) {
    configTime(0, 0, deviceConfig.ntpServer, "pool.ntp.org", "time.nist.gov");
    Debug.println("NTP sync started (UTC) – preferred: " + String(deviceConfig.ntpServer));
  } else {
    configTime(0, 0, "pool.ntp.org", "time.nist.gov");
    Debug.println("NTP sync started (UTC) – using pool.ntp.org / time.nist.gov");
  }

  // ── ASCOM Alpaca server (Arduino WebServer on port 11111) ─────────────────
  setupAlpacaServer();

  // ── Web UI (port 80) + WebSocket thermal stream (port 81) ────────────────
  initWebUI();

  // ── OTA firmware updates ──────────────────────────────────────────────────
  ElegantOTA.begin(&webUiServer);

  // ── MQTT / Home Assistant autodiscovery ───────────────────────────────────
  setupMQTT();

  // ── Rain / snow sensor (relay + RS485 Modbus) ────────────────────────────
  if (deviceConfig.rainEnabled) rainSensorSetup();

  // ── Safety sensor UDP broadcast (DDA-compatible) ──────────────────────────
  rainSafetyBroadcastSetup();

  // ── DHT ambient temperature / humidity sensor (optional) ─────────────────
  // For I2C-based BMP sensors, run a full address scan first to confirm what's on the bus.
  if (deviceConfig.dhtType == 3 || deviceConfig.dhtType == 4) {
    Debug.println("--- I2C full scan (BMP sensor configured) ---");
    bool anyFound = false;
    for (uint8_t addr = 1; addr < 127; addr++) {
      Wire.beginTransmission(addr);
      if (Wire.endTransmission() == 0) {
        // Read chip ID register (0xD0) to identify the device
        Wire.beginTransmission(addr);
        Wire.write(0xD0);
        Wire.endTransmission(false);
        Wire.requestFrom(addr, (uint8_t)1);
        uint8_t chipId = Wire.available() ? Wire.read() : 0xFF;
        Debug.printf("  I2C device at 0x%02X  chipId=0x%02X", addr, chipId);
        if      (addr == 0x29 || addr == 0x28) Debug.print(" (TSL2591)");
        else if (addr == 0x33)                 Debug.print(" (MLX90640)");
        else if (chipId == 0x58)               Debug.print(" (BMP280)");
        else if (chipId == 0x60)               Debug.print(" (BME280)");
        else if (chipId == 0x50)               Debug.print(" (BMP388)");
        else if (chipId == 0x42)               Debug.print(" (BMP390)");
        Debug.println("");
        anyFound = true;
      }
    }
    if (!anyFound) Debug.println("  No I2C devices found on bus!");
    Debug.println("--- I2C full scan complete ---");
  }
  if (deviceConfig.dhtType != 0) dhtSetup();

  // ── Health watchdog ───────────────────────────────────────────────────────
  watchdogSetup();

  // ── History ring buffers ──────────────────────────────────────────────────
  historySetup();
  skyHistorySetup();

  // ── Initial sensor reads ──────────────────────────────────────────────────
  if (sensorReady)     readSensor();
  if (brightnessReady) readBrightness();
  updateThermalSnapshot();  // prime the /thermal.jpg cache before first request

  Debug.println("Setup complete.");
}

// ---------------------------------------------------------------------------
// loop()
// ---------------------------------------------------------------------------
void loop()
{
  // Close history buckets on schedule.
  historyLoop();

  // Service ASCOM Alpaca HTTP requests and UDP discovery.
  alpacaServer.handleClient();
  handleAlpacaDiscovery();

  // Service web UI HTTP requests and WebSocket frames.
  handleWebUI();

  // Service OTA.
  ElegantOTA.loop();

  // Service MQTT.
  mqttLoop();

  // Health watchdog – heap monitor, periodic log.
  watchdogLoop();

  // Rain / snow sensor – relay read + periodic Modbus poll.
  if (deviceConfig.rainEnabled) {
    rainSensorLoop();
    historyAccumulateRain(rainIsWet());
  }

  // Sky history hour clock – always runs (SQM/clear-sky tracking doesn't
  // depend on the rain sensor); rain wet-time is only folded in above when
  // deviceConfig.rainEnabled is true.
  skyHistoryLoop();

  // Safety sensor UDP broadcast – periodic keep-alive + immediate on state change.
  rainSafetyBroadcastLoop();

  // DHT ambient sensor – periodic read.
  if (deviceConfig.dhtType != 0) dhtLoop();

  // Honour an ASCOM PUT /refresh request from a connected client.
  if (skyConditions.isRefreshRequested()) {
    skyConditions.clearRefreshRequest();
    if (sensorReady) readSensor();
    return;
  }

  // Periodic thermal read at FRAME_INTERVAL_MS.
  if (sensorReady && (millis() - lastSensorRead >= FRAME_INTERVAL_MS)) {
    readSensor();
  }

  // Periodic brightness read at BRIGHTNESS_INTERVAL_MS.
  if (brightnessReady && (millis() - lastBrightnessRead >= BRIGHTNESS_INTERVAL_MS)) {
    readBrightness();
  }
}

// ---------------------------------------------------------------------------
// readSensor()
// ---------------------------------------------------------------------------
void readSensor()
{
  if (mlx.getFrame(thermalFrame) != 0) {
    Debug.println("MLX90640 getFrame() error – skipping this cycle");
    return;
  }

  // Ambient temperature: prefer DHT when enabled and valid (MLX die temp runs high
  // due to self-heating; an external DHT gives a true ambient reference).
  float ambientTemp = (deviceConfig.dhtType != 0 && dhtData.valid)
                      ? dhtData.temperature
                      : mlx.getTa(false);

  skyConditions.update(thermalFrame, ambientTemp);

  historyAccumulateThermal(
    skyConditions.getSkyTemperature(),
    skyConditions.getMinTemperature(),
    skyConditions.getMaxTemperature(),
    skyConditions.getMedianTemperature(),
    skyConditions.getAmbientTemperature(),
    skyConditions.getCloudCoverMean(),
    skyConditions.getCloudCoverPixel());

  if (skyConditions.hasBrightnessData())
    skyHistoryAccumulateCloud(skyConditions.getCloudCover(), skyConditions.getLux());

  broadcastThermalFrame();
  broadcastSensorState();

  lastSensorRead = millis();

  Debug.printf("Sky: %.2f C  Min: %.2f C  Max: %.2f C  Median: %.2f C  Amb: %.2f C\n",
    skyConditions.getSkyTemperature(),
    skyConditions.getMinTemperature(),
    skyConditions.getMaxTemperature(),
    skyConditions.getMedianTemperature(),
    skyConditions.getAmbientTemperature());
}

// ---------------------------------------------------------------------------
// readBrightness()
// ---------------------------------------------------------------------------
void readBrightness()
{
  // Auto-gain state – persists across calls.
  static tsl2591Gain_t currentGain    = TSL2591_GAIN_MAX;
  static uint8_t       lastIntegration = 0xFF;  // force apply on first call

  // Apply integration time from config (only when it changes).
  if (deviceConfig.tsl2591Integration != lastIntegration) {
    tsl.setTiming((tsl2591IntegrationTime_t)deviceConfig.tsl2591Integration);
    lastIntegration = deviceConfig.tsl2591Integration;
  }

  uint32_t lum = tsl.getFullLuminosity();
  uint16_t ch0 = lum & 0xFFFF;
  uint16_t ch1 = lum >> 16;
  float    lux = tsl.calculateLux(ch0, ch1);  // -1 on overflow

  if (lux < 0) {
    // Saturated – step down one gain level and wait for the next read.
    switch (currentGain) {
      case TSL2591_GAIN_MAX:  currentGain = TSL2591_GAIN_HIGH; break;
      case TSL2591_GAIN_HIGH: currentGain = TSL2591_GAIN_MED;  break;
      case TSL2591_GAIN_MED:  currentGain = TSL2591_GAIN_LOW;  break;
      default: break;  // Already at LOW; nothing more to try
    }
    tsl.setGain(currentGain);
    Debug.println("TSL2591: saturated, gain decreased");
  } else {
    skyConditions.updateBrightness(lux);
    historyAccumulateBrightness(skyConditions.getLux(), skyConditions.getSqm());
    skyHistoryAccumulateSqm(skyConditions.getSqm(), skyConditions.getLux());
    Debug.printf("Lux: %.4f  SQM: %.2f mag/arcsec^2\n",
      skyConditions.getLux(), skyConditions.getSqm());

    // Signal very weak – step up one gain level for the next read.
    // Threshold of 256/65535 provides hysteresis against the saturation boundary.
    if (ch0 < 256 && currentGain != TSL2591_GAIN_MAX) {
      switch (currentGain) {
        case TSL2591_GAIN_LOW:  currentGain = TSL2591_GAIN_MED;  break;
        case TSL2591_GAIN_MED:  currentGain = TSL2591_GAIN_HIGH; break;
        case TSL2591_GAIN_HIGH: currentGain = TSL2591_GAIN_MAX;  break;
        default: break;
      }
      tsl.setGain(currentGain);
      Debug.println("TSL2591: weak signal, gain increased");
    }
  }

  lastBrightnessRead = millis();
  broadcastSensorState();
}

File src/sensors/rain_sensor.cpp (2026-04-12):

/*
 * Rain / Snow Sensor – ZTS-3000-YUX-NO1RO1-H
 * Relay input (IO38) + RS485 Modbus RTU via MAX3485ED (IO39/40/41)
 */

#include "rain_sensor.h"
#include "config.h"
#include "config_store.h"
#include "../debug/debug.h"
#include "../webserver/web_ui_handler.h"

RainData rainData = {};

static HardwareSerial &rs485 = Serial2;

// ---------------------------------------------------------------------------
// Modbus CRC16
// ---------------------------------------------------------------------------

static uint16_t crc16(const uint8_t *buf, uint8_t len)
{
    uint16_t crc = 0xFFFF;
    for (uint8_t i = 0; i < len; i++) {
        crc ^= buf[i];
        for (uint8_t b = 0; b < 8; b++)
            crc = (crc & 1) ? ((crc >> 1) ^ 0xA001) : (crc >> 1);
    }
    return crc;
}

// ---------------------------------------------------------------------------
// Single Modbus register read (Function Code 03)
//
// Returns true and sets *val on success.
// The DE/RE# control pin on IO39 is asserted HIGH (TX) for the request,
// then pulled LOW (RX) after flush() so the reply can be received.
// ---------------------------------------------------------------------------

static bool modbusRead(uint8_t addr, uint16_t reg, uint16_t *val)
{
    // Build 8-byte Modbus RTU request
    uint8_t req[8];
    req[0] = addr;
    req[1] = 0x03;          // Read Holding Registers
    req[2] = reg >> 8;
    req[3] = reg & 0xFF;
    req[4] = 0x00;
    req[5] = 0x01;          // quantity = 1 register
    uint16_t c = crc16(req, 6);
    req[6] = c & 0xFF;
    req[7] = c >> 8;

    // Discard any stale bytes in the RX buffer
    while (rs485.available()) rs485.read();

    // --- Transmit ---
    // Assert TX mode, send all 8 bytes, wait for the last bit to leave the
    // shift register, then immediately release back to RX mode.
    // flush() on ESP32 Arduino blocks until the UART shift register is empty,
    // so the line is idle when we pull DE LOW.
    // The extra 150 µs (~1.5 bit-times at 9600) gives the line a clean idle
    // state before the transceiver switches direction.
    digitalWrite(RAIN_RS485_DE_PIN, HIGH);
    rs485.write(req, 8);
    rs485.flush();
    delayMicroseconds(150);
    digitalWrite(RAIN_RS485_DE_PIN, LOW);   // now listening

    // --- Receive ---
    // Expected response: addr(1) + FC(1) + byte_count(1) + data(2) + CRC(2) = 7 bytes
    unsigned long t0 = millis();
    while (rs485.available() < 7 && millis() - t0 < 200) { /* spin */ }

    int avail = rs485.available();
    if (avail < 7) {
        return false;   // caller reports state transitions; don't spam on every poll
    }

    uint8_t resp[7];
    rs485.readBytes(resp, 7);

    Debug.printf("[Rain] RS485 rx: %02X %02X %02X %02X %02X %02X %02X\n",
        resp[0], resp[1], resp[2], resp[3], resp[4], resp[5], resp[6]);

    // Validate CRC
    uint16_t rxCrc   = (uint16_t)resp[5] | ((uint16_t)resp[6] << 8);
    uint16_t calcCrc = crc16(resp, 5);
    if (rxCrc != calcCrc) {
        Debug.printf("[Rain] CRC mismatch: received=%04X  calculated=%04X\n", rxCrc, calcCrc);
        return false;
    }

    // Validate header (address, function code, byte count for 1 register = 2)
    if (resp[0] != addr || resp[1] != 0x03 || resp[2] != 0x02) {
        Debug.printf("[Rain] Unexpected header: %02X %02X %02X\n",
            resp[0], resp[1], resp[2]);
        return false;
    }

    *val = ((uint16_t)resp[3] << 8) | resp[4];
    return true;
}

// ---------------------------------------------------------------------------
// Baud-rate scanner – tries common rates and reports any bytes received.
// Returns the working baud rate, or 0 if nothing responded.
//
// TODO: if baud scan finds nothing, add Phase 2 – address scan (0x01..0x20)
//       at 9600 baud in case the sensor shipped with a non-default address.
//       Next debug step: re-try with A/B swapped now that 12V supply is
//       confirmed good, then run the address scan if still no response.
// ---------------------------------------------------------------------------

static const uint32_t BAUD_CANDIDATES[] = { 4800, 9600, 19200, 38400, 115200 };

static uint32_t baudScan()
{
    Debug.println("[Rain] --- RS485 baud scan (addr=0x01, reg 0x0000) ---");

    for (uint32_t baud : BAUD_CANDIDATES) {
        rs485.end();
        rs485.begin(baud, SERIAL_8N1, RAIN_RS485_RX_PIN, RAIN_RS485_TX_PIN);
        delay(50);

        uint8_t req[8] = { RAIN_MODBUS_ADDR, 0x03, 0x00, 0x00, 0x00, 0x01, 0, 0 };
        uint16_t c = crc16(req, 6);
        req[6] = c & 0xFF;
        req[7] = c >> 8;

        while (rs485.available()) rs485.read();
        digitalWrite(RAIN_RS485_DE_PIN, HIGH);
        rs485.write(req, 8);
        rs485.flush();
        delayMicroseconds(150);
        digitalWrite(RAIN_RS485_DE_PIN, LOW);

        unsigned long t0 = millis();
        while (rs485.available() == 0 && millis() - t0 < 300) { /* wait */ }

        int avail = rs485.available();
        if (avail > 0) {
            String raw = "";
            while (rs485.available()) {
                char buf[4];
                sprintf(buf, "%02X ", rs485.read());
                raw += buf;
            }
            Debug.printf("[Rain]   %6u baud: GOT %d byte(s): %s\n", baud, avail, raw.c_str());
            if (avail >= 7) {
                Debug.printf("[Rain] Working baud rate: %u\n", baud);
                return baud;
            }
        } else {
            Debug.printf("[Rain]   %6u baud: no response\n", baud);
        }
        delay(50);
    }

    Debug.println("[Rain] --- baud scan complete: no response at any rate ---");
    return 0;
}

// ---------------------------------------------------------------------------
// Register scan – run once we know the baud rate is correct.
// ---------------------------------------------------------------------------

static void registerScan()
{
    Debug.println("[Rain] --- RS485 register scan (addr=0x01, regs 0x0000..0x0007) ---");
    for (uint16_t r = 0; r <= 7; r++) {
        uint16_t val = 0;
        if (modbusRead(RAIN_MODBUS_ADDR, r, &val)) {
            Debug.printf("[Rain]   reg[0x%04X] = %u  (0x%04X)\n", r, val, val);
        } else {
            Debug.printf("[Rain]   reg[0x%04X] = <no response>\n", r);
        }
        delay(50);
    }
    Debug.println("[Rain] --- scan complete ---");
}

// ---------------------------------------------------------------------------
// Public API
// ---------------------------------------------------------------------------
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

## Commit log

2026-03-22 Baseline: ESP32-S3 ASCOM Alpaca ObservingConditions device
    Full working implementation including:
    - MLX90640 thermal camera (sky temp, frame stats, WebSocket live view)
    - TSL2591 lux sensor with auto-gain (sky brightness + SQM)
    - ASCOM Alpaca ObservingConditions API on port 11111
    - Web UI on port 80 (home, setup, OTA)
    - WebSocket thermal stream on port 81
    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
2026-03-22 Add time-series history and Trends page
    Ring buffers:
    - Hi-res: 30-second buckets, last 60 minutes (120 slots)
    - Lo-res: 15-minute buckets, last 24 hours (96 slots)
    Both store avg/min/max for sky temp, frame min/max/median, ambient, lux, SQM.
    New endpoints:
    - GET /trends – Trends page with three canvas charts
    - GET /history.json?minutes=N – Streamed JSON (chunked, no large heap alloc)
    Short views (5/30/60 min) use 30-second hi-res buckets;
    long views (2/6/12/24 h) use 15-minute lo-res buckets.
    Charts (custom canvas renderer, no CDN dependencies):
    - Temperature: sky, frame min/max, median, ambient with lo/hi shading
    - Sky Brightness: lux with lo/hi shading
    - Sky Quality: SQM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
    [SkyConditions_90640.ino]
2026-03-22 v0.2.1 - cloud cover, persistent config, PSRAM JPEG, real-time UI
    - Cloud cover estimation from ambient-sky temperature deficit; exposed on
    home page stat grid, ASCOM /cloudcover endpoint, and Trends chart
    - Persistent calibration via NVS (Preferences): sqmOffset, cloudClearDelta,
    cloudOvercastDelta; editable on Setup page with POST /save_config
    - JPEG snapshot now uses fmt2jpg_cb with pre-allocated static buffers,
    eliminating runtime heap allocation failures; scaledBuf placed in PSRAM
    via heap_caps_malloc for ESP32-S3 N16R8; scale raised to 10x (320x240)
    - SQM offset applied in updateBrightness(); cloud cover accumulated in
    history ring buffers as HM_CLOUD metric
    - Real-time uptim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
    [SkyConditions_90640.ino, config.h]
2026-03-22 v0.3.0 - Alpaca Conform compliance, TSL2591 brightness, NTP config
    - Full ASCOM Conform Universal 4.2.1 compliance (0 errors, 0 issues)
    - TSL2591 sky brightness and SQM implemented (SkyBrightness, SkyQuality)
    - Configurable NTP server (preferred + pool.ntp.org / time.nist.gov fallbacks)
    - Alpaca UDP discovery on Core 0 FreeRTOS task (reliable under sensor load)
    - LatestUpdateTime via TimeSinceLastUpdate("") returning seconds as double
    - SensorDescription error code 1024 for unimplemented sensors
    - AveragePeriod: numeric validation (HTTP 400) + negative value (HTTP 200+error)
    - SQM reference lux configurable via web setup page
    - Remove rain_monitor reference subfolder
    - Add README.md; update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
    [SkyConditions_90640.ino, config.h]
2026-03-22 v0.3.1: dual cloud cover, CDS colormap, thermal matrix endpoint
    - Add per-pixel cloud cover method alongside existing mean method;
    both are calculated every frame, trended on charts, and a Setup
    page toggle selects which value is reported to Alpaca
    - Per-pixel region is configurable: centre FOV or full frame with
    adjustable edge exclusion (default 2 px)
    - Replace jet colormap with ClearDarkSky 11-stop palette (dark navy
    = clear/cold → near-white = overcast/warm) in C++ fillRGBBuffer
    and JS WebSocket canvas renderer
    - Anchor colormap scale to cloud-cover calibration thresholds
    (ambient ± clearDelta / overcastDelta) so minor temperature
    gradients in a clear sky stay in the dar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
    [SkyConditions_90640.ino, config.h]
2026-03-24 v0.4.0: rain/snow sensor relay + RS485 Modbus infrastructure
    - Add rain_sensor.h/.cpp: ZTS-3000-YUX relay input (IO38) and RS485
    Modbus RTU via MAX3485ED (IO39/40/41); baud-rate scanner at boot
    - Home page shows Rain/Snow wet/dry status with relay and RS485 sources
    - MQTT state JSON includes rain_wet, rain_relay, rain_modbus fields
    - MQTT HA discovery adds binary_sensor (moisture) for rain detection
    - RS485 address scan deferred as TODO pending A/B wire confirmation
2026-03-25 Rain sensor: relay/RS485 mode toggle + live relay state via WebSocket
    - Add rainMode to DeviceConfig (0=Relay, 1=RS485) persisted in NVS
    - rainSensorSetup(): skip RS485 init and baud scan in relay mode
    - rainSensorLoop(): only poll the active path
    - rainIsWet(): returns only active-mode result
    - broadcastRainState(): sends {"rain":"WET/DRY"} text message over WS port 81
    on every relay state change (relay mode only)
    - Home page rain box: mode label, DOM ids rain-state/rain-sub for live update,
    shows only active mode sub-text
    - Home page JS: handles text WS messages to update rain box without page reload
    - Setup page: Rain Sensor section with mode dropdown (takes effect after reboot)
    Co-A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
    [rain_sensor.cpp]
2026-03-25 v0.4.1: live sensor state updates + adaptive lux precision
    - broadcastSensorState() pushes ambient temp, cloud cover (mean+pixel),
    lux, and SQM as JSON text over the existing port-81 WebSocket after
    every thermal and brightness read
    - Home page JS handler updates those stat boxes without a page reload
    - Lux display uses adaptive precision: ≥1 lux → 1 dp, ≥0.1 → 3 dp,
    ≥0.001 → 4 dp, below that → scientific notation
    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
2026-03-30 v0.4.2: XIAO board support, SafetyMonitor, relay pin rework, sensor throttle
    Board / hardware
    - Add BOARD_XIAO_SENSE define; board-conditional I2C pins (GPIO5/6 XIAO, GPIO8/9 Dev)
    - I2C bus recovery (9-pulse bit-bang) before Wire.begin() to clear lockups
    - I2C pin auto-scanner at boot: tries candidate SDA/SCL pairs, inits sensors on first hit
    Rain sensor
    - XIAO two-pin relay scheme: GPIO7 (D8) driven HIGH, GPIO8 (D9) INPUT_PULLDOWN
    replaces single IO38 pull-to-GND; board-conditional via #if RAIN_RELAY_DRIVE_PIN >= 0
    - New rainEnabled NVS config flag (default true); setup/loop guarded by flag
    - Status page shows "--" / "Disabled" instead of false "DRY" when sensor is off
    - Setup page: rela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
    [SkyConditions_90640.ino, config.h, rain_sensor.cpp]
2026-03-30 v0.4.3: optional DHT ambient temperature/humidity sensor
    Hardware
    - DHT11/22 on D7 (GPIO44, XIAO Grove D6/D7 connector) – single data line,
    Grove connector supplies VCC+GND; D6 left unused
    - DHT_TYPE DHT11 by default; change to DHT22 in config.h for ±0.5°C precision
    Behavior (opt-in, dhtEnabled=false by default)
    - When enabled: DHT temperature replaces MLX90640 die temperature as ambient
    reference for cloud-cover delta calculations (die temp runs high due to
    self-heating; external DHT gives true ambient)
    - Falls back to MLX die temp automatically if DHT read fails or not yet valid
    - Humidity exposed as live ASCOM Alpaca ObservingConditions/humidity property;
    returns NotImplement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
    [SkyConditions_90640.ino, config.h, dht_sensor.cpp]
2026-03-30 v0.4.4: DHT type selectable at runtime (Disabled/DHT11/DHT22)
    Replace dhtEnabled bool with dhtType (0=disabled, 1=DHT11, 2=DHT22) throughout.
    Setup page now shows a dropdown instead of a checkbox, with precision specs for
    each option inline. DHT object allocated at boot time with the configured type
    so no recompile needed to switch between DHT11 and DHT22.
    [SkyConditions_90640.ino, config.h, dht_sensor.cpp]
2026-03-30 v0.4.5: Switch device Conform fixes + setup page redirects
    - Switch device: switchIdOk() now distinguishes non-numeric Id (HTTP 400,
    protocol error) from out-of-range integer Id (HTTP 200 + ErrorNumber 1025,
    ASCOM semantic error); fixes Protocol Check ISSUEs where bad-value Id was
    silently parsed as 0 and returned valid data
    - Switch device: handleSwReadOnly() validates Id before returning 1024, so
    invalid Id returns 1025 and valid-but-read-only Id returns 1024 per ASCOM spec
    - Alpaca server: setup/UI routes redirect to web UI port 80 (/ → /, /setup → /setup)
    - Switch device routes registered and included in discovery
    - Discovery task stack increased to 4096 bytes (was 2048, caus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
    [config.h]
2026-03-30 Add /setup/v1/<type>/0/setup redirect routes
    Alpaca clients use /setup/v1/<type>/<n>/setup (not /api/v1/...) for the
    device setup URL. Register redirects for all three devices so browsers
    land on the web UI setup page at port 80.
2026-03-30 v0.5.0: README refresh + version bump
    - README updated to cover all features added since 0.3.1: XIAO board
    support, rain sensor + SafetyMonitor, DHT ambient sensor, Switch device,
    MQTT/HA autodiscovery, Alpaca setup page redirects, Conform status for
    all three devices, updated wiring tables and file structure
    - Bump version to 0.5.0
2026-03-31 v0.5.1: Add BMP180 and BMP280 ambient temperature sensor options
    Extends the ambient sensor selection (Setup page) to include BMP180
    (I2C addr 0x77) and BMP280 (I2C addr 0x76/0x77) alongside DHT11/DHT22.
    Both BMP sensors share the existing SDA/SCL bus with no extra GPIO.
    Pressure is displayed on the home page and included in WebSocket frames.
    Humidity Alpaca endpoint restricted to DHT types only.
2026-03-31 v0.5.2: Web debug console + BMP280 ambient sensor support
    Adds a /console page with a live, auto-scrolling debug log viewer.
    Consecutive identical messages collapse to (×N) to suppress floods.
    Pause, Clear, and Copy buttons included. Polls /console.json every 2 s.
    Also adds BMP280 as ambient sensor option 4 alongside existing
    BMP180 (option 3), DHT11, and DHT22.
2026-04-03 v0.5.3: BME280 support, WiFi scan/reconnect, thermal smoothing, FOV box fix
    - Add BME280 ambient sensor (dhtType=5): temperature, pressure, humidity;
    explicit setSampling() call fixes humidity register ordering bug
    - WiFi scan & reconnect without credential reset: GET /wifi/scan returns
    nearby APs as JSON; POST /wifi/connect calls WiFi.begin() in place
    - Live thermal view: bicubic interpolation (imageSmoothingQuality=high)
    replaces nearest-neighbor upscaling; pre-allocate offscreen canvas
    - Cloud cover region bounding box now tracks cloudPixelRegion setting
    (full-frame or centre FOV) independent of which method is reported to Alpaca
    - Update README and CLAUDE.md: library list, config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
    [SkyConditions_90640.ino, config.h, dht_sensor.cpp]
2026-04-03 Add 3D-printed enclosure files and BOM to README
    - Add Enclosure/ with 12 STL/3MF files: housing body, lid, bracket,
    sensor insert plate, Stevenson screen, TPU gaskets and cable grommet
    - README: 3D-Printed Enclosure section (print materials, assembly notes,
    heatset insert sizes, lens holder and strain relief details)
    - README: Bill of Materials (XIAO ESP32-S3, Grove board, MLX90640,
    TSL2591, rain sensor, Uxcell lens holder, strain relief, hookup wire)
    [Housing - Base.stl, Housing - Bracket Clamp.stl, Housing - Bracket.stl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]
2026-04-05 Fix web server becoming unresponsive after extended uptime
    WebSocket connections from browsers that close abruptly (tab close,
    sleep, crash) were never detected as dead because no heartbeat was
    configured. These zombie connections held TCP PCBs indefinitely,
    and once the lwIP shared socket pool filled up the WebServer could
    no longer accept new connections. MQTT was unaffected because it
    uses an already-established persistent TCP connection.
    - wsServer.enableHeartbeat(15s, 3s, 1): pings every 15 s, drops
    client after one missed pong (18 s max to reclaim a dead socket).
    - Explicit webUiServer.client().stop() after chunked-transfer
    responses (/history.json, /thermalmatrix) so those sock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
2026-04-05 Add health watchdog: heap monitor, periodic console logging
    watchdog.h/.cpp checks every 60 s:
    - Free heap and running low-water mark → warn at <30 KB, restart at <15 KB
    - Free PSRAM
    - WebSocket client count (>4 logged as a notice; zombie accumulation indicator)
    - Uptime (optional WATCHDOG_MAX_UPTIME_DAYS compile-time guard available)
    All output goes through Debug so reports appear in the web console at
    /console as well as on serial. getWsClientCount() accessor added to
    web_ui_handler so the watchdog doesn't need to touch wsServer directly.
    https://claude.ai/code/session_01HfFFAxtmUF2SgV7k2jsrE7
    [SkyConditions_90640.ino]
2026-04-05 Fix TypeError: Failed to fetch on Trends page
    client().stop() inside chunked-transfer handlers was closing the TCP
    socket before the Arduino WebServer's post-handler cleanup could send
    the HTTP chunked terminator (0\r\n\r\n). The browser received an
    incomplete response and threw TypeError: Failed to fetch.
    Replace client().stop() with a Connection: close response header sent
    before the chunked body begins. The browser closes its end after the
    complete response arrives; the server-side socket is freed via the TCP
    FIN shortly after, without breaking the response.
    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
2026-04-07 Add rain/snow status to trends page history
    - Add HM_RAIN metric to history ring buffer (avg fraction-wet per 30s bucket)
    - Call historyAccumulateRain() each loop iteration when rain sensor is enabled
    - Render a color-block rain chart on the Trends page (green=dry, red=wet)
    - getTrendsPage() now takes rainEnabled flag; chart omitted when sensor is off
2026-04-12 Updated enclosure STL's
    [Bottom Cap.stl, Fin Ring.stl, Neck.stl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]
2026-04-12 Add DDA-compatible safety sensor UDP broadcast
    Broadcasts rain sensor safe/unsafe state on UDP (port 23435 by default)
    in the Dark Dragon Astronomy park-sensor JSON format, allowing devices
    like a Roll-Off Roof controller to discover and react to rain conditions.
    New fields isSafe, rainState, ambTemp (null before first MLX frame).
    Port, interval (default 30 s), and enabled state are runtime-configurable
    via the Setup page with no reboot required.
    [SkyConditions_90640.ino, config.h]
2026-04-12 Reorganize source files into src/ subdirectories
    Moves all .h/.cpp files (except config.h, config_store.h/.cpp which
    are included by every module and benefit from staying at the sketch
    root) into categorized subdirectories under src/:
    src/debug/ – debug wrapper
    src/alpaca/ – ASCOM Alpaca server + UDP discovery
    src/sensors/ – MLX90640, TSL2591, DHT/BMP, rain sensor, history
    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
2026-04-12 Update README for v0.6.0
    - Add DDA safety sensor UDP broadcast to features and port summary
    - Add three new safety broadcast settings to configuration table
    - Update file structure section to reflect src/ subdirectory layout
    - Add tools/udp_monitor.py to file structure
2026-04-12 Fix udp_monitor.py: add timeout, SO_REUSEADDR, Ctrl-C handling
    - settimeout(1.0) unblocks recvfrom periodically so Ctrl-C is responsive
    - SO_REUSEADDR allows immediate restart without waiting for port release
    - Wrap recvfrom in its own try/except to handle socket.timeout cleanly
    - Update README with DDA broadcast feature, port 23435, new config settings,
    and reorganized src/ file structure
2026-08-30 Add 90-day rain history calendar (v0.6.1)
    New Rain History page (/rainhistory) shows a month-view calendar of
    accumulated rain/snow duration per day, similar to other DDA sensors'
    history views. Backed by a new persistent hourly ring buffer
    (src/sensors/rain_history.h/.cpp): 2160 buckets of seconds-wet per
    epoch-hour, written to NVS on each hour rollover so it survives
    reboot. A power-off or unsynced-clock gap is recorded as zero rain
    for the missed hours rather than left undefined.
    Hourly UTC data is served from GET /rainhistory.json?days=N (1-90);
    the browser re-buckets it into local calendar days so the calendar
    reflects the viewer's own time zone, with color-coded day cells,
    prev/next m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
    [SkyConditions_90640.ino, config.h]
2026-08-30 Show compiled-in board name in Setup page and boot log
    Adds BOARD_NAME (set alongside the existing BOARD_XIAO_SENSE /
    BOARD_ESP32S3_DEV pin selection in config.h) and surfaces it on the
    Setup page's Hardware card and in the boot log, so which board a
    given firmware build targets is visible at runtime without needing
    to cross-reference I2C pin numbers.
2026-08-30 Auto-detect board pinout profile from Arduino IDE board selection
    Replaces the hand-toggled BOARD_XIAO_SENSE/BOARD_ESP32S3_DEV #define
    with auto-detection based on ARDUINO_XIAO_ESP32S3, the macro the
    esp32 core defines for whichever board is selected in Tools > Board.
    This is what actually drifted out of sync in the first place (the
    firmware said XIAO but nobody remembered), so it should track the
    compiler's own board selection instead of a manually maintained flag.
    A manual override (uncomment one #define) still exists for board
    variants auto-detection doesn't recognise.
    Also surfaces the raw ARDUINO_BOARD id (IDE_BOARD_ID) on /setup and
    in the boot log, and flags BOARD_AUTO_FALLBACK visib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
    [SkyConditions_90640.ino, config.h]
2026-08-30 Surface thermal JPEG buffer (PSRAM) allocation status remotely
    scaledBuf, the 230 KB staging buffer /thermal.jpg needs, was
    previously only diagnosable via a repeating "scaledBuf not
    allocated" line in /console with no explanation of why. Track
    whether it landed in PSRAM, fell back to internal heap, or failed
    outright, and surface that on /setup's Hardware card (with free
    PSRAM alongside it) and in /thermal.jpg's error response, pointing
    at Tools > PSRAM > OPI PSRAM in Arduino IDE as the fix when it
    failed entirely.
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2026-10-01 Add fixed/floating heatmap range option
    Setup -> Imaging gains a Heatmap Range selector. Floating (default)
    keeps the existing scale anchored to ambient minus the cloud-cover
    deltas; Fixed maps the palette to a configurable min/max (default
    -45 to +45 C). The range is applied via a shared getDisplayRange()
    helper to both the live WebSocket frame and /thermal.jpg, and the
    home page colour bar labels follow the selected mode. Cloud cover
    calculations are unchanged.
    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
2026-10-01 Heatmap: warm tail in fixed mode and magenta hot-pixel marker
    Fixed mode now runs the ClearDarkSky blue-to-white palette from Min up
    to 0 C, then a white-yellow-orange-red tail up to Max (default raised
    to +60 C). Pixels above the hot threshold - the top of the fixed range,
    or ambient + 20 C in floating mode - get palette index 255 and render
    magenta, so a sub-pixel sun stands out instead of saturating.
    heatmapColor() is now the single palette definition: the JPEG
    snapshot uses it directly and the home page receives a 256-entry
    lookup table generated from it, replacing the duplicated JS palette.
    The colour bar gains a magenta cap labelled with the hot threshold.
    Cloud cover calculations are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
    [config.h]
2026-10-01 Heatmap: disable magenta hot-pixel marker, clamp to end colour
    Add HEATMAP_HOT_MARKER (config.h, default 0). With it off, pixels past
    either end of the scale clamp to the end colour - dark red at the top
    of the fixed range - and the colour bar drops its magenta cap and shows
    a '>=' top label. Setting it to 1 restores the marker unchanged.
    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
    [config.h]
2026-10-01 Heatmap: runtime hot-marker toggle, smooth MLX90640 chess-pattern noise
    The magenta hot-pixel marker is now a Setup checkbox (heatmapHotMarker,
    NVS key heatHot, off by default) instead of a config.h compile-time
    flag, so it can be flipped without reflashing.
    fillPaletteIndices() also applies a 3x3 box average to the colour
    mapping only, cancelling the MLX90640's per-pixel chess-pattern noise
    (two interleaved sub-reads that rarely match exactly, most visible as
    a checkerboard on an otherwise-uniform clear sky). Genuine single-pixel
    extremes (e.g. the sun) are exempt from the averaging so they still
    clamp to the scale's end colour instead of being diluted. ASCOM
    readings, cloud cover, and the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
    [config.h]
2026-10-11 Alpaca: serve Temperature/Humidity/Pressure/DewPoint from ambient sensor (v0.6.4)
    Fixes #5.
    - Temperature comes from the configured DHT/BMP/BME sensor; the MLX90640
    die temperature is used only when no ambient sensor is configured.
    - Pressure (BMP180/BMP280/BME280) and DewPoint (Magnus formula, DHT/BME280)
    are now implemented.
    - Humidity, Pressure and DewPoint have SensorDescription and
    TimeSinceLastUpdate support, based on a new dhtData.lastUpdateMs.
    - Implemented-ness depends only on dhtType so property, description and
    age always agree; a configured sensor without a valid read returns 1026.
    - TimeSinceLastUpdate("") includes the ambient sensor's last read.
    - Bump version to 0.6.4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
2026-10-13 MQTT: publish humidity/pressure to Home Assistant; fix thermal image entity (v0.6.5)
    - Add humidity and pressure to the MQTT state JSON when the configured
    ambient sensor provides them and has had a first valid read.
    - Publish HA discovery for Humidity (%) and Pressure (hPa) sensors; publish
    an empty retained config to remove them when the sensor type no longer
    supports them.
    - Drop image_encoding "none" from the image entity config. HA only accepts
    "b64" or "raw", so the entity was rejected; omitted means raw binary.
    - Move envHasTemperature/Humidity/Pressure() into dht_sensor.h and use them
    from Alpaca, MQTT and the Web UI WebSocket broadcast.
    - Grow the state JSON document from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
2026-10-17 Cloud cover: ambient-compensated thresholds, smoothing, AveragePeriod median (v0.7.0)
    Implements issue #9:
    - A: thresholds shift by cldAmbSlope x (ambient - cldAmbRef), plus an
    optional dew-point term; slopes default to 0 (legacy behaviour).
    - B: optional EMA on the cloud-cover ambient (cldAmbTau), reset on first
    frame, ambient-source change, or a >3 C jump.
    - C: Alpaca CloudCover, the Switch and MQTT cloud_cover report the median
    over AveragePeriod (hours, per ASCOM). Stored under new key avgPeriodH
    (default 0) so old seconds-based values aren't reinterpreted. Saving it
    from Setup now applies immediately.
    - D: effective thresholds on the home page and in MQTT
    (cloud_clear_eff, c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
2026-10-19 Web UI style guide port; optional multi-source NTP and UTC offset (v0.7.1)
    Web UI (per WEB_UI_STYLE_GUIDE.md, shared with ror_controller):
    - One shared stylesheet with the guide's design tokens; 1040 px centred
    column, capped table/input widths, global status-dot colours, toggle
    switches, blue/red button rules. Template strings are ASCII-only.
    - Every page: header, h1, version line, nav + live status bar (sky, rain
    safety, ambient, WiFi, MQTT, clock) with a red error line.
    - New GET /api/status: the bar's single 2 s poll also fills data-live cells
    and drives data-clock displays from the device's unix_ms.
    - Setup page split into tabs and streamed tab by tab; Post/Redirect/Get back
    t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
